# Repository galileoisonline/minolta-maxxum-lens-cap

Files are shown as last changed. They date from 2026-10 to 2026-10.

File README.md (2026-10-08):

# Minolta Maxxum 5000 — 49 mm Front Lens Cap (pinch lock)

Redesigned **front** caps for the Maxxum 5000 kit lens (**Minolta AF 50 mm f/1.7**, filter **49 × 0.75**), with an **inward-pinch lock** like the OEM **LF-1349**.

> The older friction push-on STLs in `stl/*.stl` did **not** work well — they are kept only for reference. Use **`stl/oem_spring/`** or **`stl/pinch/`**.

## What lens / what cap

| | |
|--|--|
| Camera | Minolta Maxxum 5000 |
| Kit lens | AF 50 mm f/1.7 |
| Filter thread | **Ø49 mm × 0.75** |
| OEM cap | **LF-1349** |
| Mechanism | Squeeze pads **inward** → tabs/arches retract → insert or remove; release → locks in the filter thread |

Full measurement notes: [`docs/DIMENSIONS.md`](docs/DIMENSIONS.md)

## Print this (recommended): OEM-style shell + spring

Files in [`stl/oem_spring/`](stl/oem_spring/):

| File | Qty | Role |
|---|-----|---|
| `minolta_49mm_oem_shell.stl` | 1 | Outer lid |
| `minolta_49mm_oem_spring_clip.stl` | 1 | Inward-pinch spring that locks in the threads |
| `minolta_49mm_oem_PREVIEW_assembled.stl` | — | Visual only, do not print |

### Print settings

**Shell**

- PLA or PETG, 0.16–0.20 mm layers, 3–4 walls, 15–25% infill  
- Face down on the bed  

**Spring clip (critical)**

- **PETG**, **100% infill**, **0.12–0.16 mm** layers, 3+ walls  
- Seam away from the arch tips  
- No supports if oriented flat  

### Assembly

1. Clean spring seat and pad slots in the shell.  
2. Compress the spring pads slightly and seat the clip under the face ledges.  
3. Pads should sit in the face slots so you can pinch them.  
4. Pinch → push onto the 49 mm filter thread → release to lock.

## Alternate: sliding center-pinch (2 latches)

Files in [`stl/pinch/`](stl/pinch/):

| File | Qty |
|---|-----|
| `minolta_49mm_pinch_cap_body.stl` | 1 |
| `minolta_49mm_pinch_latch.stl` | 1 |
| `minolta_49mm_pinch_latch_mirror.stl` | 1 |

Latches print in PETG; body in PLA/PETG. Slide latches into the body guides so teeth poke through the skirt windows.

## Thread engagement (design intent)

| State | Tip / plug OD | Purpose |
|---|---|---|
| Pinched | ~47.3–47.8 mm | Clears filter minor Ø ≈ 48.19 mm |
| Locked | ~49.5–49.7 mm | Catches past filter major Ø 49.00 mm |

## Regenerate (optional)

Needs CadQuery (e.g. a venv):

```bash
python3 -m venv .venv
.venv/bin/pip install cadquery
.venv/bin/python generate_oem_spring_cap.py   # recommended
.venv/bin/python generate_pinch_cap.py        # alternate
```

Tune diameters in the script constants if your printer runs oversized/undersized.

## Community parts worth knowing

- [Minolta 49 mm Lens Cap Spring (Printables)](https://www.printables.com/model/927966-minolta-49mm-lens-cap-spring) — replacement spring tested on Maxxum lenses  
- [Front Lens Caps All Sizes — ThomPatterson](https://www.printables.com/model/352819-front-lens-caps-all-sizes) — spring-fit main+inserts, author-tested at 49 mm  
- [Minolta 49 mm lens cap clip](https://www.printables.com/model/1592707-minolta-49mm-lens-cap-clip)

## License

MIT — see [`LICENSE`](LICENSE). Not affiliated with Minolta or Sony.

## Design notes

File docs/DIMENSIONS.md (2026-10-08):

# Lens & Cap Dimensions — Minolta Maxxum 5000

Research notes used for the v2 pinch / OEM-spring redesign.

## Camera kit lens

| Item | Value | Source |
|---|---|---|
| Camera | Minolta Maxxum 5000 (α-5000 / Dynax 5000), 1986 | camera-wiki |
| Original kit lens | **Minolta AF 50 mm f/1.7** | camera-wiki |
| Mount | Minolta A / Sony A bayonet | — |
| Filter thread | **Ø49 mm, pitch 0.75 mm** | Minolta specs, ISO 1948 series |
| Max lens diameter | 65.5 mm | Minolta / mhohner |
| Lens length | ~38–46 mm (focus extension) | mhohner / Wikipedia |
| Weight | ~170–186 g | specs |
| OEM front cap P/N | **LF-1349** (49 mm front) | KEH / Minolta accessory lists |

Confirm on your glass: the front ring should read something like `Ø49mm` or `49mm`.

## Filter thread geometry (what the cap must grip)

Photographic filter threads follow the ISO metric profile (ISO 68 / ISO 724 family) in the ISO 1948 size series.

For **49 × 0.75**:

| Parameter | Formula / value |
|---|---|
| Major diameter \(d\) | **49.00 mm** |
| Pitch \(P\) | **0.75 mm** |
| Pitch diameter | \(d - 0.649519\,P\) ≈ **48.513 mm** |
| Minor diameter (internal flat crest) | \(d - 1.082532\,P\) ≈ **48.188 mm** |

Functional meaning for a front cap:

1. The cap’s **pilot / plug** must fit inside the female filter bore → OD ≲ minor (~48.2 mm) when latches are retracted.
2. The **locking teeth / spring arches** must expand into the thread → tip OD ≳ major (~49.0 mm) when released.
3. A **lead-in chamfer** on the teeth lets you push the cap on without pinching first (OEM behavior).
4. Keep the face clear of the front element — typical AF 50/1.7 filter-stack depth leaves a few mm; designs here keep insertion ~5–6 mm and open in the center.

## OEM LF-1349 mechanism (what “inward push” means)

Maxxum-era Minolta front caps are **not** friction push-ons. They use an internal sprung latch:

- Two opposing pads stick up through the lid (side / near-center pinch).
- **Squeeze pads inward** → spring arches retract from the filter thread.
- **Release** → arches expand into the thread and lock the cap.
- The plastic spring is the famous failure point (Photrio repair threads; Printables replacement springs by Philip Stanz et al., tested on Maxxum 35–70 and 70–210).

Typical aftermarket / OEM 49 mm center-pinch envelope (commercial listings):

| Envelope | Approx. |
|---|---|
| Outer diameter | ~54–55 mm |
| Thickness / height | ~8–9 mm |
| Mass | ~10 g |

## Design targets used in this repo (v2)

### Shared thread targets

| Feature | Target (mm) | Why |
|---|---|-----|
| Plug / lip OD | **47.6–47.8** | Clears minor (48.19) with FDM margin |
| Lock tip OD (rest) | **49.5–49.7** | Positive catch past major 49.0 |
| Lock tip OD (pinched) | **~47.3** | Clears minor for removal |
| Pinch travel / side | **~1.2–1.4** | Comfortable finger squeeze |
| Moving clearance | **0.30** | FDM sliding fit baseline |
| Face OD | **54.6–54.8** | Covers filter rim, OEM-like |
| Skirt / insert depth | **5.8–6.2** | Engages first threads, clears glass |

### Variant A — `stl/oem_spring/` (closest to Minolta)

| Part | File | Notes |
|---|---|---|
| Shell / lid | `minolta_49mm_oem_shell.stl` | Rigid face + spring seat + pad slots |
| Spring clip | `minolta_49mm_oem_spring_clip.stl` | Dual arches + inward pinch pads |

Print spring in **PETG, 100% infill, 0.12–0.16 mm** layers. Shell can be PLA or PETG.

### Variant B — `stl/pinch/` (sliding center-pinch)

| Part | File | Notes |
|---|---|---|
| Body | `minolta_49mm_pinch_cap_body.stl` | Guides + tab windows |
| Latch | `minolta_49mm_pinch_latch.stl` + `_mirror.stl` | Pad + tooth + flexure |

Same thread engagement numbers; uses discrete sliding latches instead of one spring ring.

## Why v1 push-on failed

The first STLs were friction / bead push-ons sized for an *outer* slip-over fit. OEM Maxxum caps **insert into** the filter thread and **lock with sprung tabs**. Without inward-pinch retractable teeth sized to minor/major, a solid plastic “cap” either will not enter the bore or will not stay locked.

## If fit is still off after printing

Measure with calipers and change only one parameter in the generators:

1. Printed plug OD vs 48.19 → adjust `PLUG_OD` / `LIP_ID`
2. Tab tip vs 49.0 → adjust `TAB_TIP_OD` / `ARCH_TIP_OD`
3. Pinch feel → spring thickness or `ARCH_THICK`
4. Elephant’s foot on open rim → enable compensation in slicer

## References

- Camera-wiki: [Minolta 5000](https://camera-wiki.org/wiki/Minolta_5000)
- Lens data: [Minolta AF 50/1.7](https://en.wikipedia.org/wiki/Minolta_AF_50mm_f/1.7), [mhohner AF50/1.7 new](https://mhohner.de/sony-minolta/onelens/af50f17new)
- Cap P/N: Minolta **LF-1349**
- Spring failure / repair: [Photrio thread](https://www.photrio.com/forum/threads/minolta-lens-cap-for-the-front-lens-fix-for-broken-spring.203021/)
- Maxxum-tested 49 mm spring: [Printables — Philip Stanz](https://www.printables.com/model/927966-minolta-49mm-lens-cap-spring)
- Proven FDM spring-fit architecture (tested 49 mm): [ThomPatterson — Front Lens Caps All Sizes](https://www.printables.com/model/352819-front-lens-caps-all-sizes)
- ISO 1948 filter thread series; ISO 724 basic metric thread dimensions

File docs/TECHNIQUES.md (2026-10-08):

# Techniques for Generating Printable Models (Lens Caps & Fit Parts)

This document summarizes the techniques needed to design and generate 3D-printable parts like a Minolta Maxxum front lens cap: from measuring the real interface, through CAD/mesh generation, to FDM design rules and fit iteration.

---

## 1. Pipeline overview

```
Measure interface → Parametric CAD / script → Solid / B-rep or CSG
       → Tessellate to mesh (STL / 3MF)
       → Validate manifold geometry
       → Slice (G-code) with DfAM-aware settings
       → Print → Fit test → Adjust parameters → repeat
```

Printable functional parts almost always need **iteration**. Treat clearances and bead interference as parameters, not one-shot guesses.

---

## 2. Know the physical interface

Before modeling, identify what the part must mate with.

### Front lens cap (this repo)

| Fact | Value / note |
|---|---|
| Interface | Photographic filter thread on lens barrel |
| Common Maxxum kit size | **49 × 0.75** mm |
| Standard | ISO 1948 (lens/filter thread series); profile follows ISO metric (ISO 68 / ISO 724 family) |
| Pitch (≈30–86 mm filters) | **0.75 mm** |
| Below ~30 mm | Often 0.5 mm pitch |
| Above ~86 mm | Often 1.0 mm pitch |

For M49 × 0.75-class threads (ISO 724 formulas):

- Major diameter ≈ **49.00 mm**
- Pitch diameter ≈ \(d - 0.649519\,P\) ≈ **48.51 mm**
- Minor diameter (internal flat crest) ≈ \(d - 1.082532\,P\) ≈ **48.19 mm**

You do **not** always need a full thread. Three workable front-cap strategies:

1. **Push-on** — cup slips over the filter rim; internal bead/friction holds it (forgiving on FDM).
2. **Snap / spring clips** — two flexible tabs catch behind the first thread (OEM-like; needs flex + XY orientation).
3. **Screw-in** — model a female 0.75 mm thread with print clearance (precise; needs fine layers).

### Other Maxxum-related caps

- **Rear lens cap / body cap** — Minolta AF / Sony A-mount bayonet (different geometry; flange focal distance 44.5 mm is *not* the cap OD).
- Do not confuse SR/MC/MD (manual) rear caps with AF/A-mount caps.

**Measure when possible:** calipers on filter OD, thread depth, and any outer barrel lip beat nominal assumptions.

---

## 3. CAD approaches that generate printable geometry

### A. Parametric solid CAD (best for fit parts)

Tools: **FreeCAD**, **Fusion 360**, **Onshape**, **CadQuery** (Python + OpenCascade B-rep).

- Model as solids with named parameters: `filter_mm`, `clearance`, `wall`, `bead_height`.
- Export **STEP** for archival, **STL/3MF** for slicing.
- CadQuery STL export controls mesh quality via `tolerance` / `angularTolerance`.

**Why this is preferred:** fillets, exact threads, and Boolean ops stay valid solids; tessellation is a last step.

### B. CSG scripting (OpenSCAD)

- Construct with `difference()`, `union()`, `cylinder()`, etc.
- Great for fully parametric public models (`.scad` + Customizer).
- Critical rule: subtracted volumes must **extend past** the stock (not merely touch faces), or export fails with *“Object isn't a valid 2-manifold!”*
- Coincident/tangent faces that only touch (no overlap) also break manifold export.

### C. Direct mesh generation (this repo’s Python script)

- Emit triangles yourself (binary STL).
- Fine for simple lathe-like parts (caps, bushings).
- You are responsible for:
  - Consistent winding / normals
  - Watertight seams between rings
  - No gaps at segment joins
- Harder for true helical threads and complex fillets.

### D. Hybrid community pattern (best OEM-like caps)

Many Printables/Thingiverse lens caps use:

- Rigid **main** cap + separate **spring insert(s)** (PETG / high infill)
- Or FreeCAD spreadsheet parameters for filter size + spring thickness

That splits “stiff shell” from “flexing latch,” which maps well to FDM anisotropy.

---

## 4. Mesh rules the slicer actually requires

A printable mesh must be **manifold** (watertight):

1. Every edge shared by **exactly two** triangles
2. Consistent normals (outward)
3. No self-intersections
4. Positive enclosed volume
5. Prefer a **single** connected solid component per printable body

Validate outside the CAD tool when possible (Meshmixer, `trimesh`, PrusaSlicer warnings, online manifold checkers). Tool self-reports are not always enough.

**Formats:**

| Format | Role |
|---|---|
| **STL** | Universal triangle soup; no units metadata (assume mm) |
| **3MF** | Preferred modern package; units, multiple bodies, better metadata |
| **STEP** | Exact CAD exchange; not sliced directly |

Units for desktop FDM: **millimeters**.

Tessellation: enough segments that a Ø50 mm circle is not visibly polygonal (this generator uses ~96–100 segments). In OpenSCAD, raise `$fn` for cylinders that must fit round parts.

---

## 5. Design for Additive Manufacturing (DfAM) — FDM

Rules that decide whether a nice CAD model survives the printer.

### Walls & features (0.4 mm nozzle)

| Target | Guideline |
|---|---|
| Min printable wall | ≥ 1 extrusion width (~0.45 mm) |
| Reliable thin wall | ≥ **2 perimeters** (~0.9 mm) |
| Structural wall (caps) | **1.6–2.0 mm** (3–4 perimeters) |
| Tiny text / logos | Prefer emboss ≥ 0.4–0.5 mm deep/tall |

Align wall thickness to integer multiples of extrusion width when you care about surface quality.

### Overhangs, bridges, orientation

- Unsupported overhangs: aim ≤ **45–60°** from vertical (machine-dependent; some printers reach ~75°).
- Short bridges OK; long unsupported floors need supports or a redesign.
- **Print orientation is a design decision:**
  - Cap face on the bed → smooth outer face, rim printed upward
  - Snap arms should flex in the **XY** plane when possible — FDM is weaker across layer lines (Z)
- Prefer **chamfers** on bed-facing edges over large downward fillets (fillets create steep unsupported curves).

### Material choice for caps

| Material | Use |
|---|-----|
| **PLA** | Fast fit prototypes; brittle snaps |
| **PETG** | Better for springs, beads, repeated on/off |
| **TPU** | Soft push-on / bumper rings (often multi-part) |
| **ASA / ABS** | Outdoor / heat; more shrinkage → retune fits |

Spring clips: print in PETG, high perimeter count, often **100% infill** on the flexure.

---

## 6. Fit engineering (the hard part)

There is no universal clearance. Start from process baselines, then print a test.

### Clearance baselines (assembly gaps)

| Process | Typical starting clearance |
|---|---|
| FDM | ~**0.5 mm** for sliding fits; tighter after calibration |
| SLA / SLS / MJF | ~**0.3 mm** |

Prusa notes ~0.2 mm machine accuracy class, but filament shrinkage and elephant’s foot add error. Use elephant-foot compensation so the open rim of a cap stays circular.

### Strategies for lens caps

**Push-on (forgiving)**

- Cavity ID ≈ filter major + **1.5–2.5 mm**
- Internal retention bead slightly tighter (e.g. major + **1.0–1.5 mm**)
- Lead-in chamfer / ramp so the bead flexes on
- This repo’s defaults for 49 mm: cavity ≈ 51.2 mm ID, bead ≈ 50.4 mm ID

**Snap / cantilever**

- Long, tapered beams; fillet the root (≥ ~0.5× root thickness)
- Gentle entry ramp, sharper retaining face
- Deflection in XY; avoid bending across layers
- Locating lugs share shear load

**Screw-in thread (FDM)**

- Prefer coarse, large diameters (filter threads at 49 mm are printable with care)
- Layer height ≤ pitch / 4 when possible (0.75 mm pitch → ≤ 0.2 mm, better 0.12–0.16 mm)
- Add diameter clearance: internal thread oversized ~**0.2–0.4 mm**, or external undersized ~**0.1–0.2 mm**
- Print thread axis **vertical**
- Chamfer thread starts
- PETG is grippier than PLA — needs more clearance

### Iteration workflow

1. Print the looser variant first.
2. Measure with calipers (printed ID vs design ID).
3. Change **one parameter** (bead ID or clearance).
4. Keep a size ladder: loose / nominal / tight STLs (as in this repo).

Parametric source (OpenSCAD, FreeCAD spreadsheet, CadQuery, or this Python script) makes that cheap.

---

## 7. Geometry construction patterns for a cap

A typical printable front cap is a **solid of revolution** plus optional local flexures:

1. **Face disk** — closes the optical path; optional finger recess
2. **Outer skirt** — grip texture (knurls / flats); wall ≥ 1.6 mm
3. **Inner cavity** — clears glass / filter rim
4. **Retention feature** — bead, clips, or thread
5. **Lead-in** — chamfer so assembly does not scrape threads

Boolean recipe (CSG / CAD):

```text
outer_cylinder
  − inner_bore
  − (optional) face_recess
  ∪ retention_bead or clip_bodies
  − cleanup_chamfers
```

Keep a single outer shell; avoid zero-thickness sheets and non-manifold “surface only” models.

---

## 8. Toolchain checklist

| Stage | Tools | Check |
|---|---|---|
| Design | FreeCAD, Fusion, OpenSCAD, CadQuery, Python mesh | Parameters for size & clearance |
| Export | STL / 3MF | mm units, sufficient tessellation |
| Repair | PrusaSlicer, Meshmixer, `trimesh` | Manifold, one body |
| Slice | PrusaSlicer, Bambu Studio, Cura | Orientation, walls, elephant foot |
| Verify | Calipers + fit on real lens | Adjust parameters |

---

## 9. How this repo maps to the techniques

| Technique | Implementation here |
|---|---|
| Parametric size | `--size` in `generate_lens_cap.py` |
| Push-on + bead | Default and `_tight` STLs |
| Snap bead | `snap_in` STL |
| Manifold mesh | Closed ring/tube/disk triangulation |
| DfAM walls | ~1.8 mm outer wall, grip flats |
| Print orientation | Designed face-down friendly (flat top) |
| Iteration | Loose / tight variants instead of one magic fit |

For production-quality OEM clones, prefer **solid CAD + spring insert** (FreeCAD/Printables parametric caps) or CadQuery with real thread helpers. Direct STL scripts are ideal for quick, dependency-free push-on protectors.

---

## 10. References

- [Prusa Knowledge Base — Modeling with 3D printing in mind](https://help.prusa3d.com/article/modeling-with-3d-printing-in-mind_164135)
- [OpenSCAD manual — STL export / manifold errors](https://en.wikibooks.org/wiki/OpenSCAD_User_Manual/STL_Export)
- [CadQuery — import/export (STL tolerances)](https://cadquery.readthedocs.io/en/latest/importexport.html)
- [Formlabs — Designing 3D printed snap-fits](https://formlabs.com/blog/designing-3d-printed-snap-fit-enclosures/)
- [Protolabs Network — Snap-fit clearances for AM](https://www.hubs.com/knowledge-base/how-design-snap-fit-joints-3d-printing/)
- [Photo SE — Filter thread pitches (ISO 1948 series)](https://photo.stackexchange.com/questions/90951/cutting-lens-filter-accessory-threads)
- [Printables — Front Lens Caps All Sizes](https://www.printables.com/model/352819-front-lens-caps-all-sizes)
- [Printables — Parametric FreeCAD lens cap generator](https://www.printables.com/model/1388014)
- ISO 1948 (photographic lens filter threads), ISO 68 / ISO 724 (metric thread basic profile/dimensions)

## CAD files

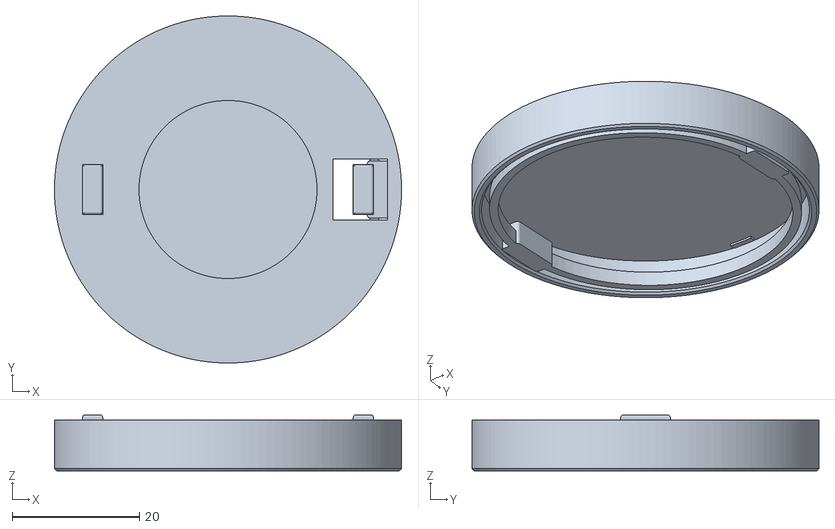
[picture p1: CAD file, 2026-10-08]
stl/oem_spring/minolta_49mm_oem_PREVIEW_assembled.stl
54.6 x 54.6 x 8.80

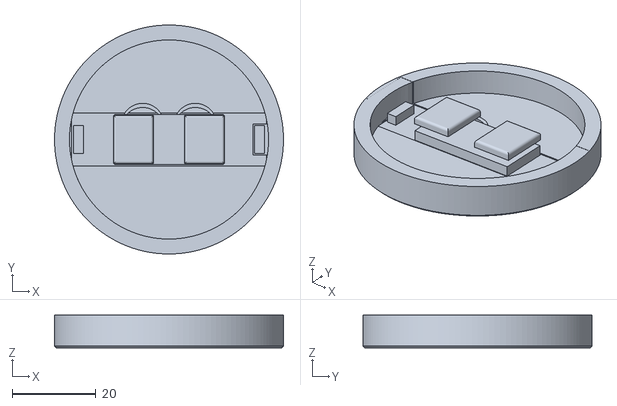
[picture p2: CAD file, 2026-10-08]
stl/pinch/minolta_49mm_pinch_cap_PREVIEW_assembled.stl
54.8 x 54.8 x 7.80

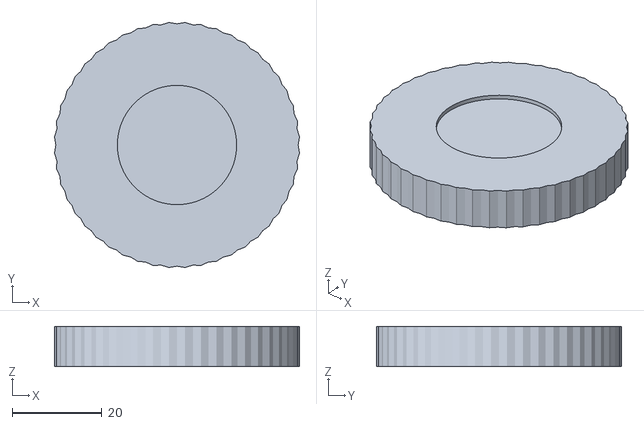
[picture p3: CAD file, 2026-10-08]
stl/minolta_maxxum_49mm_push_on_lens_cap.stl
54.7 x 54.7 x 9.00

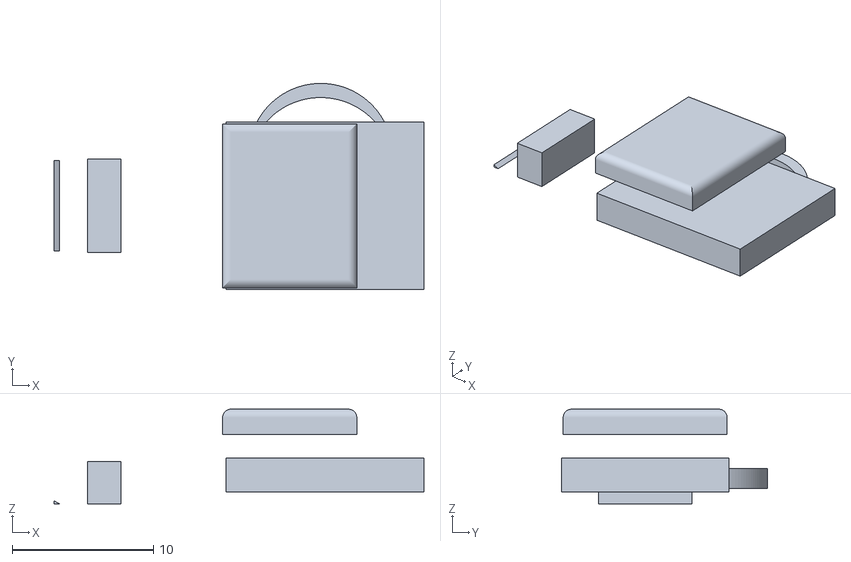
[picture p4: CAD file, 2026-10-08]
stl/pinch/minolta_49mm_pinch_latch_mirror.stl
26.2 x 14.6 x 6.70

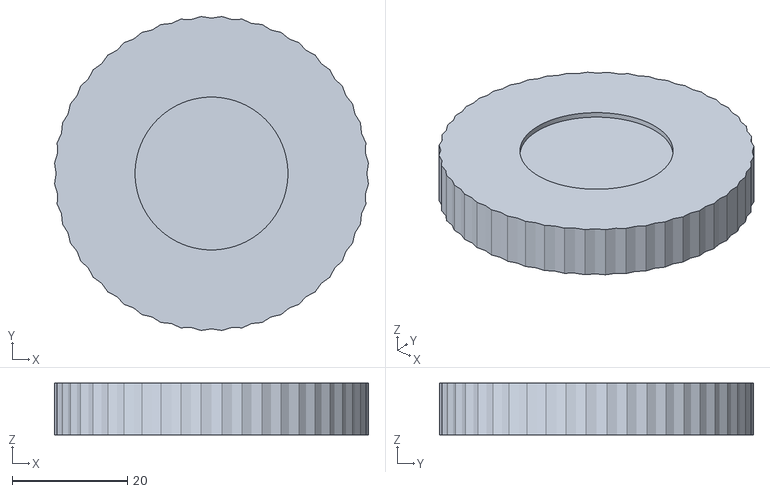
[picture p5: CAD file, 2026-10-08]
stl/minolta_maxxum_49mm_push_on_lens_cap_tight.stl
54.4 x 54.4 x 9.00

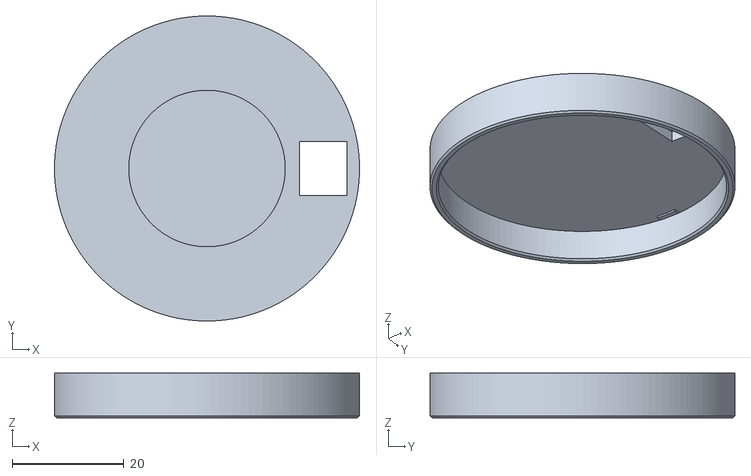
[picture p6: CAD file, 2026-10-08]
stl/oem_spring/minolta_49mm_oem_shell.stl
54.6 x 54.6 x 8.00

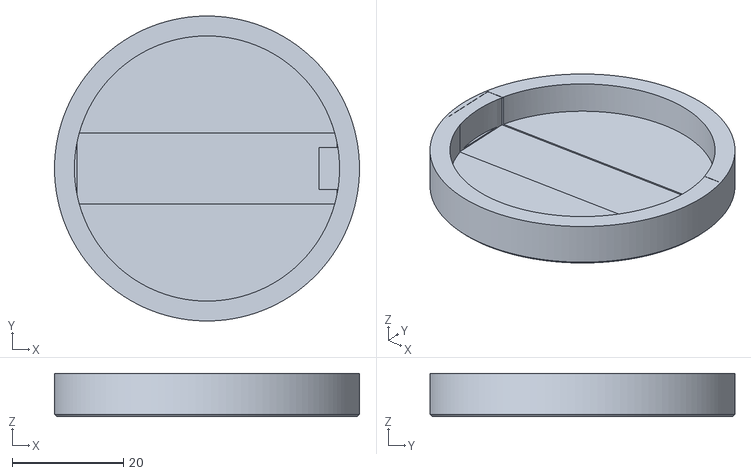
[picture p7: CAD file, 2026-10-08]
stl/pinch/minolta_49mm_pinch_cap_body.stl
54.8 x 54.8 x 7.80

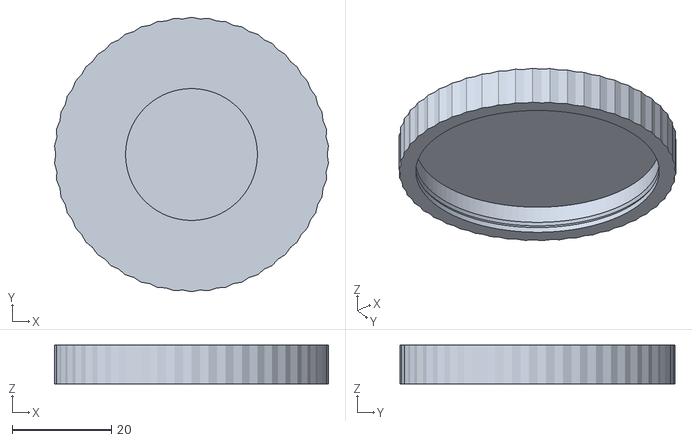
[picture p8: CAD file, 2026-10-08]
stl/minolta_maxxum_49mm_snap_in_lens_cap.stl
55.3 x 55.4 x 7.80

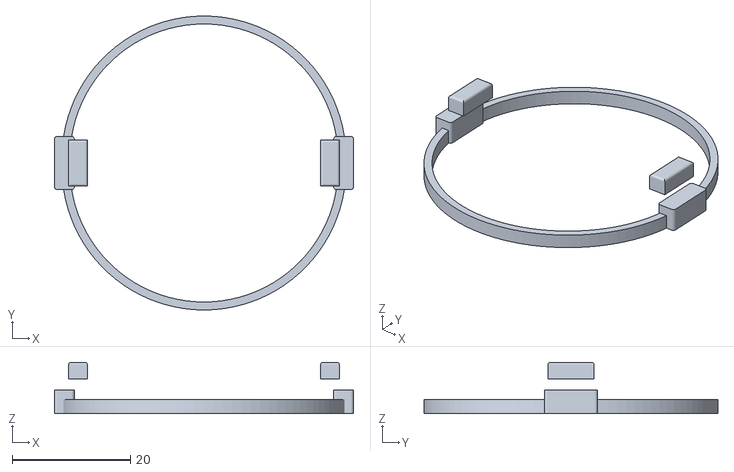
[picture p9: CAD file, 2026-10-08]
stl/oem_spring/minolta_49mm_oem_spring_clip.stl
50.6 x 49.7 x 8.65

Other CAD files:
stl/pinch/minolta_49mm_pinch_latch.stl

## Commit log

2026-10-08 Add printable Minolta Maxxum 49mm lens caps and DfAM notes
    Provide push-on and snap-in STL variants, a parametric Python generator, and research on techniques for designing FDM-printable fit parts.
    [minolta_maxxum_49mm_push_on_lens_cap.stl, minolta_maxxum_49mm_push_on_lens_cap_tight.stl, minolta_maxxum_49mm_snap_in_lens_cap.stl]
2026-10-08 Redesign 49mm front cap with inward-pinch lock
    Replace failed friction push-ons with OEM-style shell+spring and sliding center-pinch variants sized to AF 50/1.7 filter minor/major (49×0.75), plus dimension research notes.
    [minolta_49mm_oem_PREVIEW_assembled.stl, minolta_49mm_oem_shell.stl, minolta_49mm_oem_spring_clip.stl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]
